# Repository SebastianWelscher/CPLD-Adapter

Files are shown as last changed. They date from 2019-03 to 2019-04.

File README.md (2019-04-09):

# CPLD-Adapter

CPLD-Adapter board for using a Xilinx XC9536XL

Get it at Aisler: https://aisler.net/p/JLAMCPYS

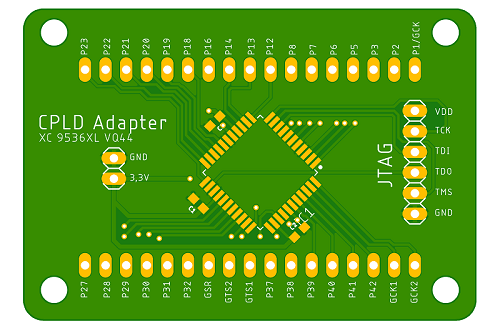
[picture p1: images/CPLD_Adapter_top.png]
Top-View
 

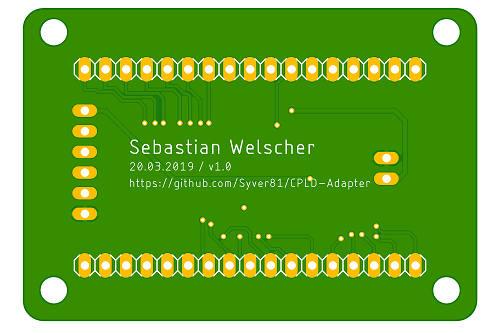
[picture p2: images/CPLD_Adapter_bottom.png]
Bottom-View


# Example

For this example we use the CPLD-Adapter board, the LED-Shield and the Switch-Shield.
For programming, we use the ISE 14.7 WebPack Software and an USB-JTAG Programmer.
You can buy it at https://eckstein-shop.de/Platform-Cable-USB or other distributors like Amazon etc.

# First step: getting and installing the software

There is a lower version of the software. You can find it on the DVD of the Platform-Cable set.

For the last ISE 14.7 WebPack and for licensing create a Account at Xilinx and dowload the last standart version, not the Win10 Version.
You have to customize some files later for working on Win10, because it´s not a supported Version for Win10. 
We do this later.

After installing you have to get a licence for the WebPack Edition.

# Second step: get it run

If you are using Win10, you have to customize some files to run the software likely stable.
Use this following steps: https://www.xilinx.com/support/answers/62380.html

# third step: Your first Project

| Part  | Port |
|--- |---|
| SW 1  | P30  |
| SW 2  | P31  |
| LED 1 | P2 |
| LED 2 | P3 |

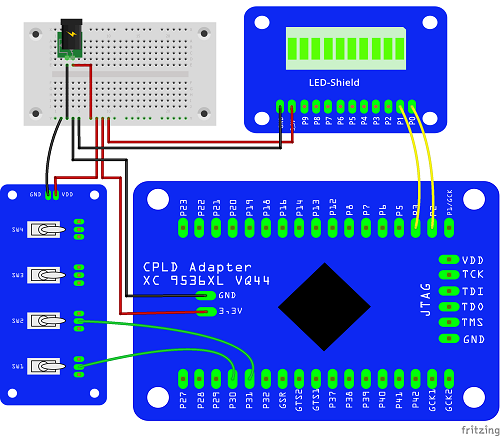
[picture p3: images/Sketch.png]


The IO-Ports of the Xilinx 9536XL are 5V tolerable so you can use 5V signals for input (from Arduino, etc). 
The output voltage depends on the supply voltage and is about 3,3V.

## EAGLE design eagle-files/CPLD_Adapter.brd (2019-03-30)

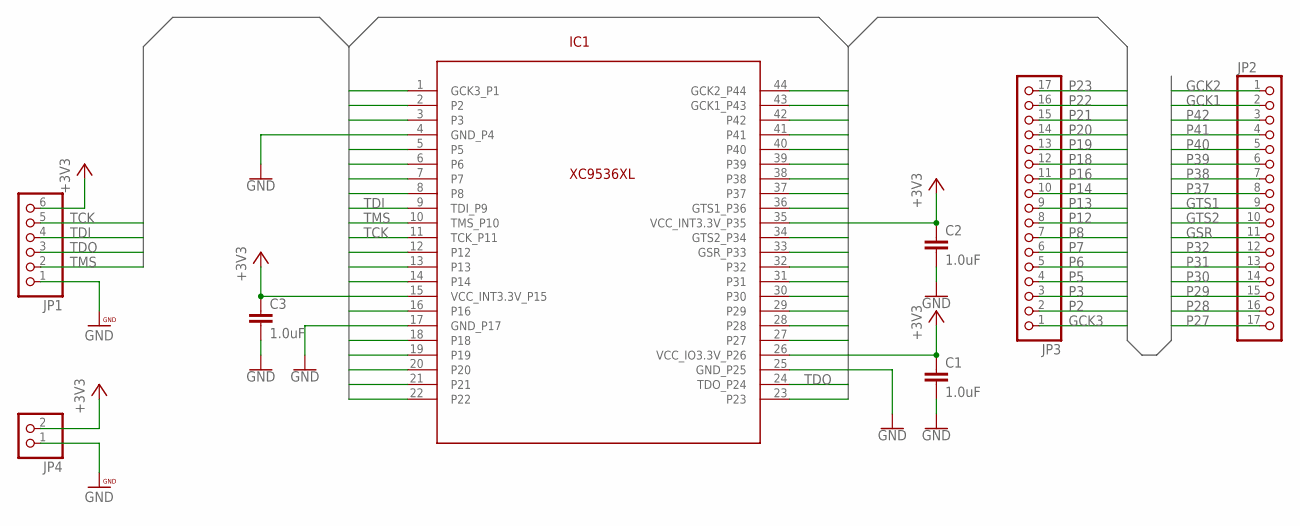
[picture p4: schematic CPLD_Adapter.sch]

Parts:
C1, C2, C3: 1.0uF; 0603
IC1: XC9536XL; QFP80P1200X1200X105-44
JP1: PINHD-1X6; 1X06
JP2, JP3: PINHD-1X17; 1X17
JP4: PINHD-1X2; 1X02

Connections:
+3V3: C1.1, C2.1, C3.1, IC1.15 (VCC_INT3.3V_P15), IC1.26 (VCC_IO3.3V_P26), IC1.35 (VCC_INT3.3V_P35), JP1.6, JP4.2
GCK1: IC1.43 (GCK1_P43), JP2.2
GCK2: IC1.44 (GCK2_P44), JP2.1
GCK3: IC1.1 (GCK3_P1), JP3.1
GND: C1.2, C2.2, C3.2, IC1.4 (GND_P4), IC1.17 (GND_P17), IC1.25 (GND_P25), JP1.1, JP4.1
GSR: IC1.33 (GSR_P33), JP2.11
GTS1: IC1.36 (GTS1_P36), JP2.9
GTS2: IC1.34 (GTS2_P34), JP2.10
P2: IC1.2, JP3.2
P3: IC1.3, JP3.3
P5: IC1.5, JP3.4
P6: IC1.6, JP3.5
P7: IC1.7, JP3.6
P8: IC1.8, JP3.7
P12: IC1.12, JP3.8
P13: IC1.13, JP3.9
P14: IC1.14, JP3.10
P16: IC1.16, JP3.11
P18: IC1.18, JP3.12
P19: IC1.19, JP3.13
P20: IC1.20, JP3.14
P21: IC1.21, JP3.15
P22: IC1.22, JP3.16
P23: IC1.23, JP3.17
P27: IC1.27, JP2.17
P28: IC1.28, JP2.16
P29: IC1.29, JP2.15
P30: IC1.30, JP2.14
P31: IC1.31, JP2.13
P32: IC1.32, JP2.12
P37: IC1.37, JP2.8
P38: IC1.38, JP2.7
P39: IC1.39, JP2.6
P40: IC1.40, JP2.5
P41: IC1.41, JP2.4
P42: IC1.42, JP2.3
TCK: IC1.11 (TCK_P11), JP1.5
TDI: IC1.9 (TDI_P9), JP1.4
TDO: IC1.24 (TDO_P24), JP1.3
TMS: IC1.10 (TMS_P10), JP1.2

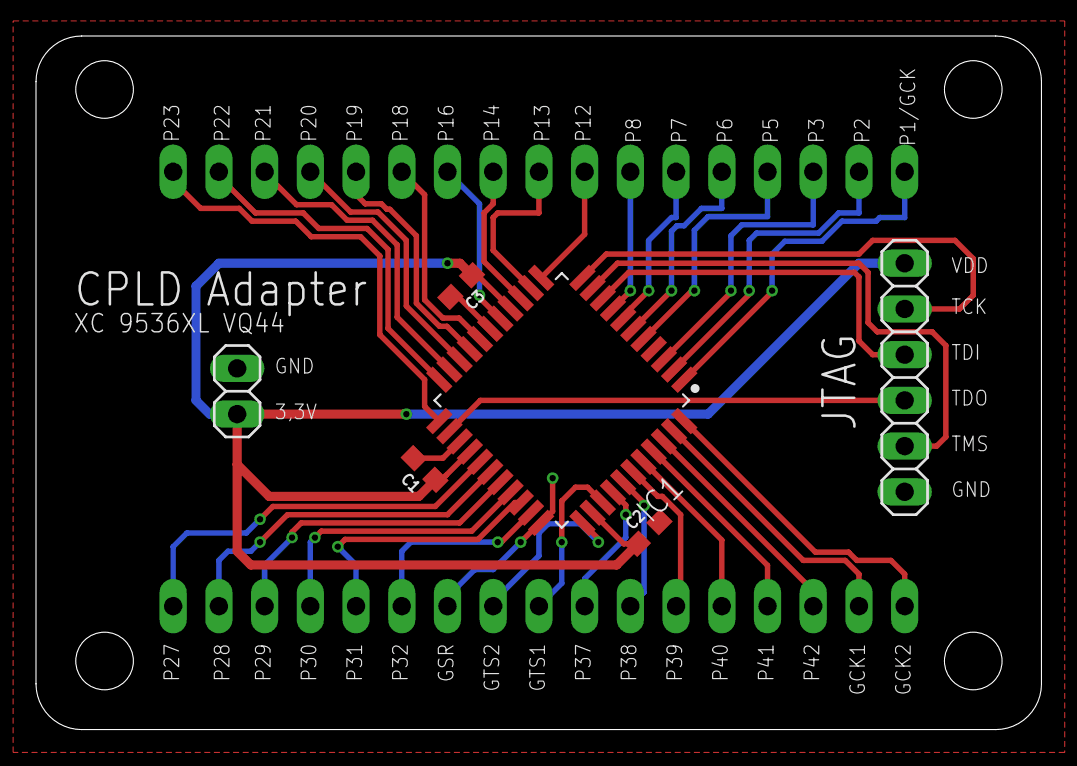
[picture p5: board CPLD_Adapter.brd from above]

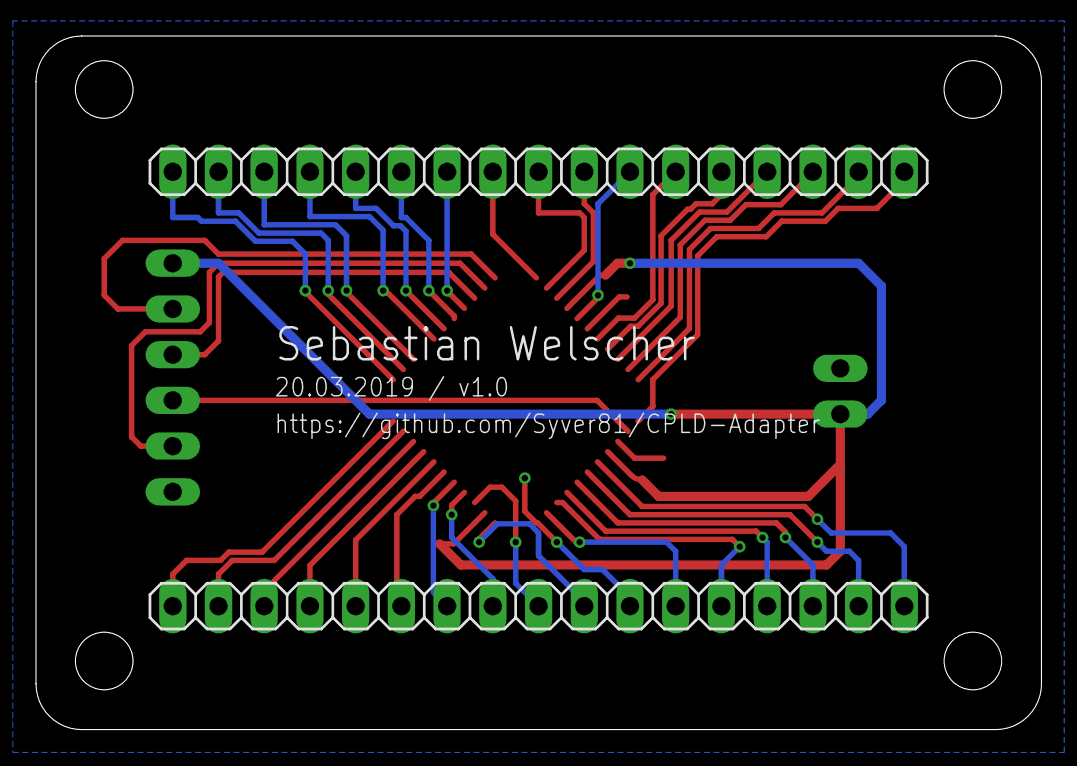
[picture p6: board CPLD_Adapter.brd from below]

Board: 2 copper layers, 55.9 x 38.5 mm, 8 parts (2 on the bottom side), 40 nets.

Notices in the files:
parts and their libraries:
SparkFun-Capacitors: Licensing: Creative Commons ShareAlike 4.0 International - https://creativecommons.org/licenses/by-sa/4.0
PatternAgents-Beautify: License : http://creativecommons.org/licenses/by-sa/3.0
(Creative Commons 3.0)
